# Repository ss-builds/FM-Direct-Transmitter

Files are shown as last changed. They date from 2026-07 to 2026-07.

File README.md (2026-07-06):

# FM Transmitter

##### Problem:

**A cheap Amazon BT FM transmitter for custom audio gives poor quality and volume loss. I'd like better integrated audio without the plug-in transmitter.**

&#x09;I could replace the factory head unit with an aftermarket unit. However, this isn't ideal: the good ones are expensive, look cheap, and I want to maintain the OEM look by keeping the original head unit. My first thought was to replace the antenna (corroded from East Coast weather), but I can't find a replacement short of a junkyard pull, which may be in the same condition or worse.

&#x09;I did find a solution online that replaces the factory antenna with a direct connection to a BT module, but there's little info on the quality of these modules and they're expensive ($100+). ***Custom has to be the way, right?***

&#x09;*(I could do a custom antenna to improve the current setup, but I want better quality than a plug-in transmitter can offer)*

##### Criteria:

* BT capable
* Upgraded audio quality (relative to current solution)
* Ease of use
* Able to switch from FM mode to BT mode with a press of a button or with connection status (will add support for both)

##### Constraints:

* Cheap as possible
* OEM+ (no replacing head-unit, no major modifications, passive)
* Interference from other signals
* Ambient temperature exceeding component operating range (automotive)

**Update 06/29/26:** Given that my Corolla's current head unit has the option for a CD player (which transmits lossless audio), I was considering to use that port to inject my BT signal into. However, this would mean taking out the head unit, probing a (very likely) proprietary communication protocol between the OEM CD player and the head unit. This will be something to consider for the future, but for now, I'll stick to something that injects directly into FM port.

**Update 07/05/2026:** Use two boards with mezzanine connectors for better EMI support & to prevent space problems while capturing the schematic.

**Update 07/06/26:** ADIsimPLL; due to constraints from capacitor sizing and to balance enough charge pump current to prevent external EMI from interfering with my VCO (MAX2606), max tunable frequency without issues is 103.9MHz, compared to the original value of 108MHz. Using 560uF hybrid polymer capacitor for C2, with 220nF C0G filter caps. To even get to a value as low as 560uF, I had to reduce the effective Kvco by using a voltage divider from ~11MHz/V to ~4.46MHz/V (reduction factor of 0.435). Otherwise, I'd be looking at values for C2 that are >1.5mF (way too high for realistic applications).

**Update 07/04/26:** Adding some basic schematic pictures to document progression. NOTE: VERY work in progress.

RF Generation _(As of 07/06/26)_:


Power: 


Oscillator capacitor shunt selection: 


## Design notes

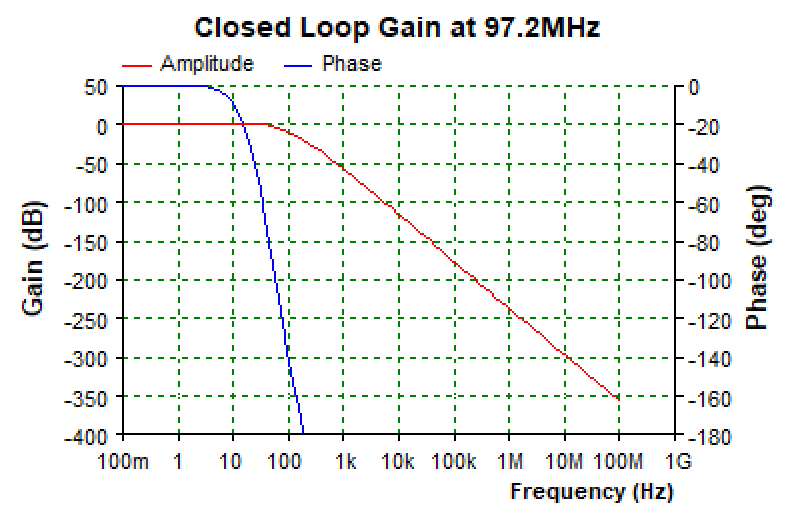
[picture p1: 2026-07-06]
ADIsimPLL/Closed_Loop_Gain.png

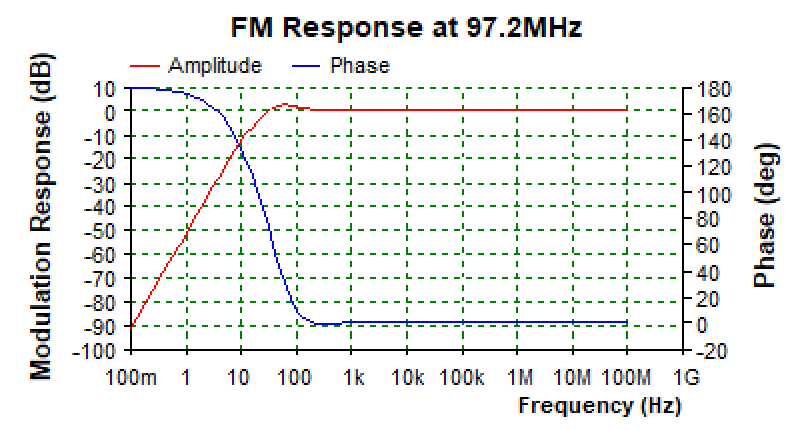
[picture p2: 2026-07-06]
ADIsimPLL/FM_Response.png

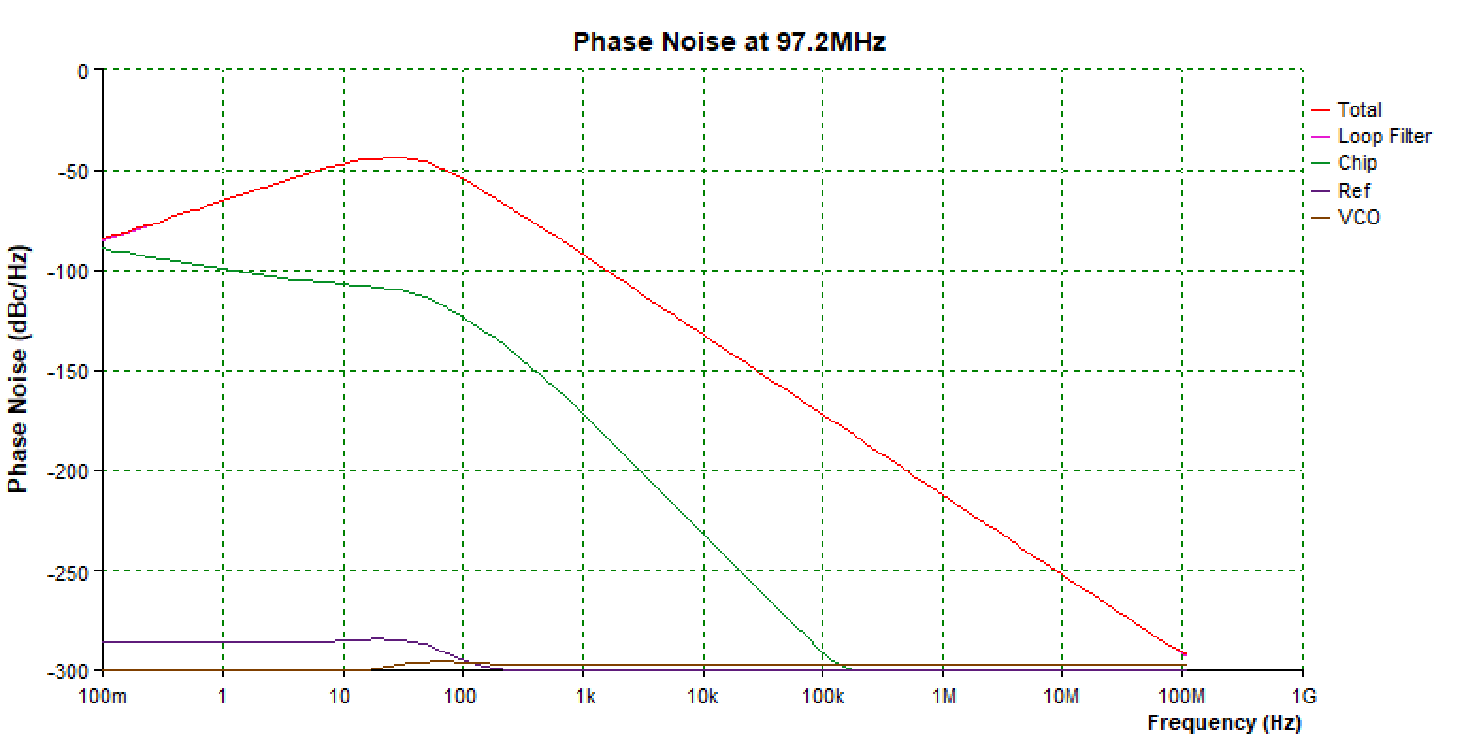
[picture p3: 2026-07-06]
ADIsimPLL/Phase_Noise.png

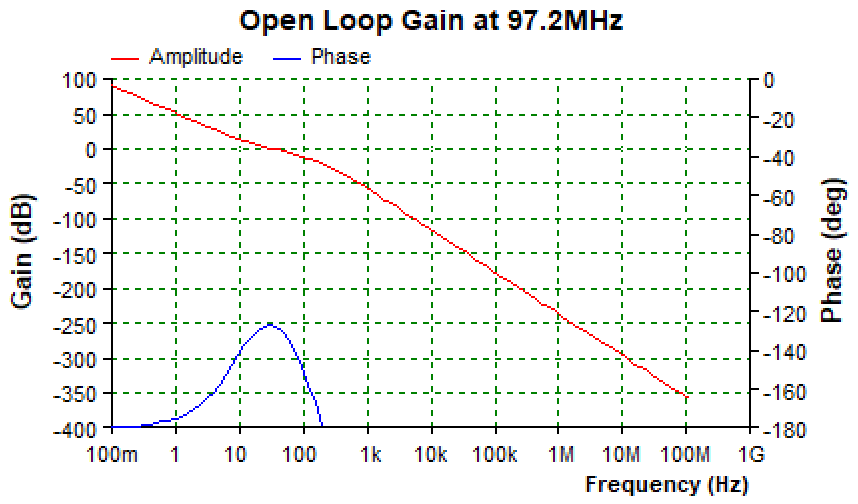
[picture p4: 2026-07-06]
ADIsimPLL/Open_Loop_Gain.png

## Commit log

2026-06-25 power in + protections added, readme better updated
    [FM Transmitter.PrjPcb, PDU.SchDoc, Schem.SchDoc]
2026-06-30 file re-organization
    [FM Transmitter.PrjPcb, PDU.SchDoc, Schem.SchDoc]
2026-07-03 implementation of MAX2606 complete; simulated cutoff response for bypass capacitor & selected chip inductor for LC oscillator
    [FM Transmitter.PrjPcb, PDU.SchDoc, RF_Gen.SchDoc]
2026-07-05 Revisions in PLL loop filter and with a lot of research got me to:
    Select an Aluminum Hybrid Polymer capacitor over Tantalum Polymer for (near) negligible qualities and lower prices
    Select an active filter to reduce overall capacitances
    [PDU.SchDoc, RF_Gen.SchDoc]
2026-07-06 Added ADIsim files + screenshots, PDU added LDO for charge pump
    [PDU.SchDoc]
2026-07-10 silent annotations added
    [BM83.SchDoc, DAC.SchDoc, FM Transmitter.PrjPcb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]
2026-07-18 RF Bypass completed + DAC setup with proper attenuation (use firmware to attenuate as well)
    [DAC.SchDoc, MCU.SchDoc, RF_Bypass.SchDoc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]
2026-07-19 Fixed up any wrong routing on DAC and MCU wired up
    Schematics completed! Now, separation into chunks for multi-board
    [DAC.SchDoc, MCU.SchDoc]
2026-07-19 Fixed up prjpcb file so all files included; begin migration to separate PCB projects
    [FM Transmitter.PrjPcb]
2026-07-20 .gitignore updated
    [BM83.SchDoc, DAC.SchDoc, DIG_PDU.SchDoc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]
2026-07-20 Designators (DIGI) updated)
    [BM83.SchDoc, ConnectorInterface.SchDoc, DAC.SchDoc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]
2026-07-21 PCB design for digital side has begun
    removal of all RF related schematics from digital layout
    Forgot to add smoothing cap to buck (47uF now added)
    Switched out bulk capacitance 33uF before the buck from an electrolytic to a hybrid capacitor for a balance of cost & size
    33uF bulk on the bottom due to collision risk
    Mounting hole moved for better routing
    [BM83.SchDoc, ConnectorInterface.SchDoc, DAC.SchDoc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]
2026-07-25 .gitignore updated for blocking PCB files (hopefully this time)
2026-07-25 Added USB port for BM83 flashing
    Reverse current blocking when RP is powered with USB IC
    Buck & 3V3 LDO implemented
    General layout pretty much done
    Begin changing some pin-outs to favor routing
    [BM83.SchDoc, DIG_PDU.SchDoc, DI_FM.PcbDoc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]
2026-07-28 More reordering of net-labels for stronger routing; if not added, using USB power from RP to power BM83 for debugging only
    [BM83.SchDoc, DigitalInterface_FM.PrjPcb, MCU.SchDoc]
2026-07-30 PCB finally laid out & done! Will update README with pictures soon
    [ConnectorInterface.SchDoc, DigitalInterface_FM.PrjPcb, MCU.SchDoc]
2026-07-31 All RF schematics migrated for mezzanine board; begin PCB
    [BM83.SchDoc, ConnectorInterface.SchDoc, DAC.SchDoc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]
2026-08-09 VCO-PLL revisions: converted PLL detection to differential over singe-ended (has option to for single-ended only
    Need to be done: change crystal to 38.4MHz to prevent injection locking of the oscillator
    [ConnectorInterface.SchDoc, DAC.SchDoc, RFInterface.PrjPcb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]
2026-09-12 Recheck all PLL values
    Checked how the boards mated with each other
    Delay in development due to semester beginning & travel
    [RF_Gen.SchDoc, RF_PDU.SchDoc]
